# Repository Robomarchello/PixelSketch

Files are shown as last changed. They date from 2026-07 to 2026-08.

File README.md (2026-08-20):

# Digital Etch A Sketch

A digital recreation of the classic Etch A Sketch, built from scratch with a Raspberry Pi Pico.

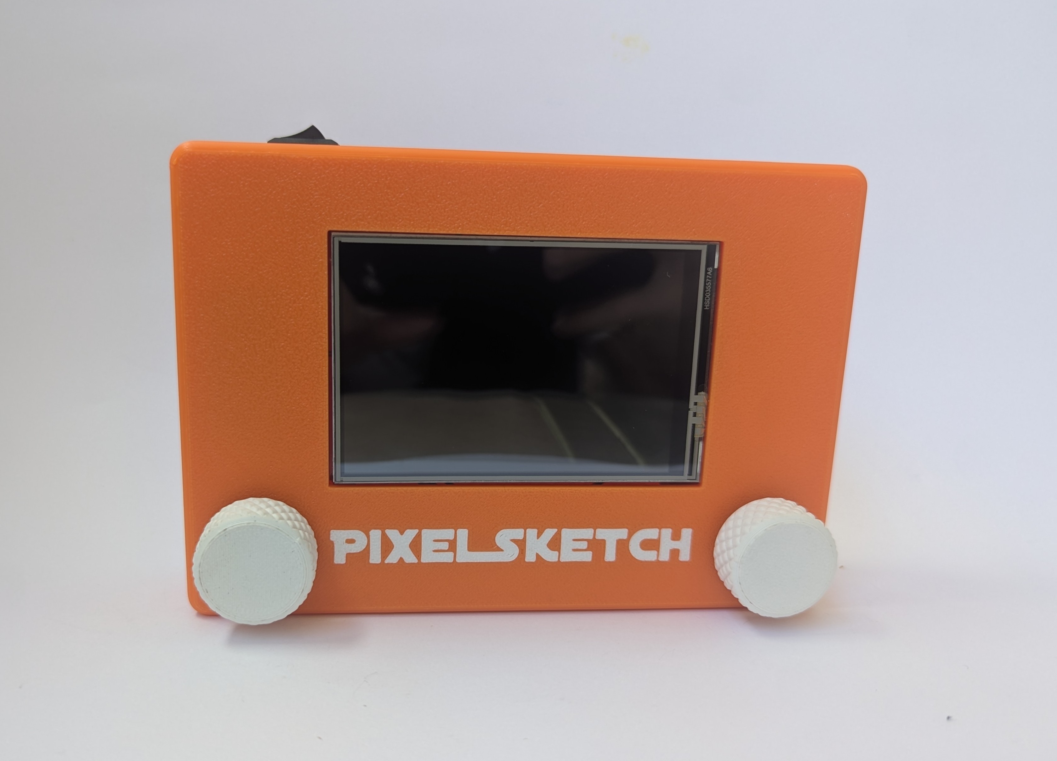
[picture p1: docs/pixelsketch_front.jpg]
front look


[View the CAD model on Onshape](https://cad.onshape.com/documents/f1feae0bb556c6484e455513/w/0b4a13cc13eba7f4db07bca6/e/b10465846ec39c7c90a8a02b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)

Wiring diagram is available in docs folder.
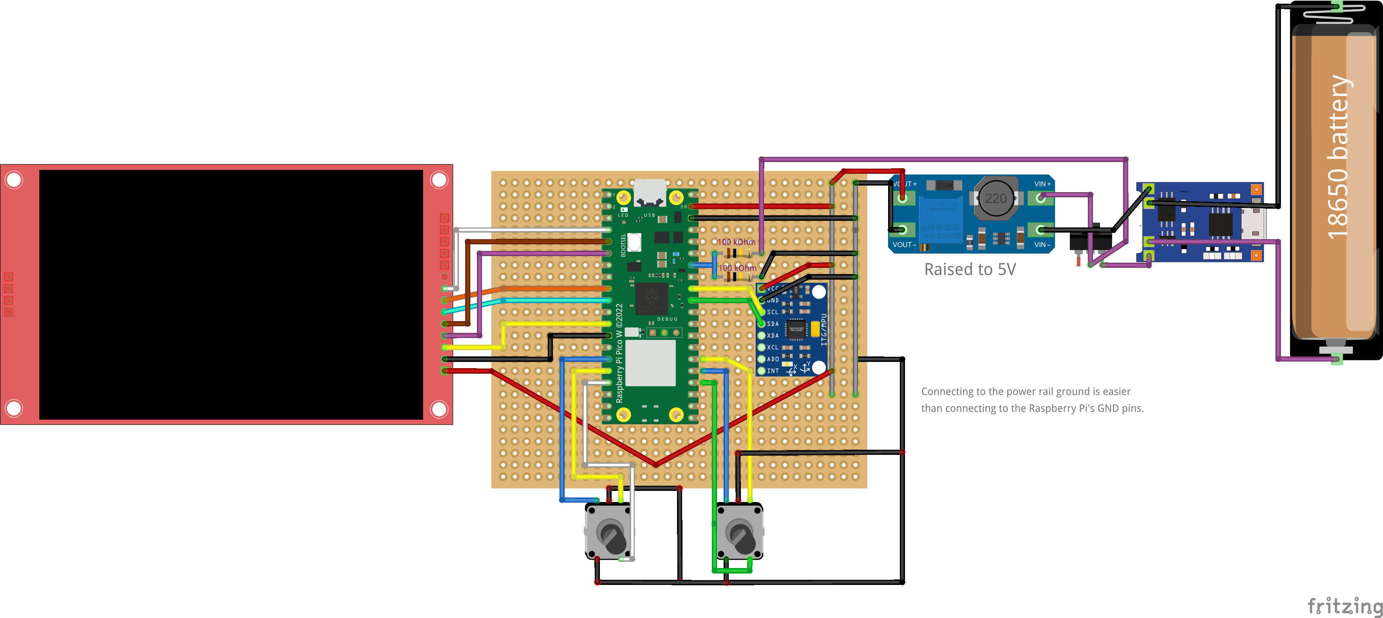
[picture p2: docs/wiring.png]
Wiring diagram

(Notice: everything should work even without boost converter) 

### Features

* 🎨 Color display
* 🎛️ Two rotary encoders for drawing
* 💾 Save drawings
* 🔋 Rechargeable battery
* 🖌️ Adjustable brush size and color
* 📦 Custom 3D-printed enclosure

## Hardware

* **Microcontroller:** Raspberry Pi Pico
* **Display:** MSP3520 3.5" SPI TFT module — ILI9488 driver
* **Rotary encoders:** 2× EC1601J-H01/15
* **Battery:** 18650 Li-ion, 1500 mAh
* **Charging module:** HW-373 (TP4056)
* **Single 18650 battery holder**
* **MPU6050**
* **70 × 90 mm Perfboard**
* **KCD11-101 Power switch**

Built as my first hardware project, using MicroPython.

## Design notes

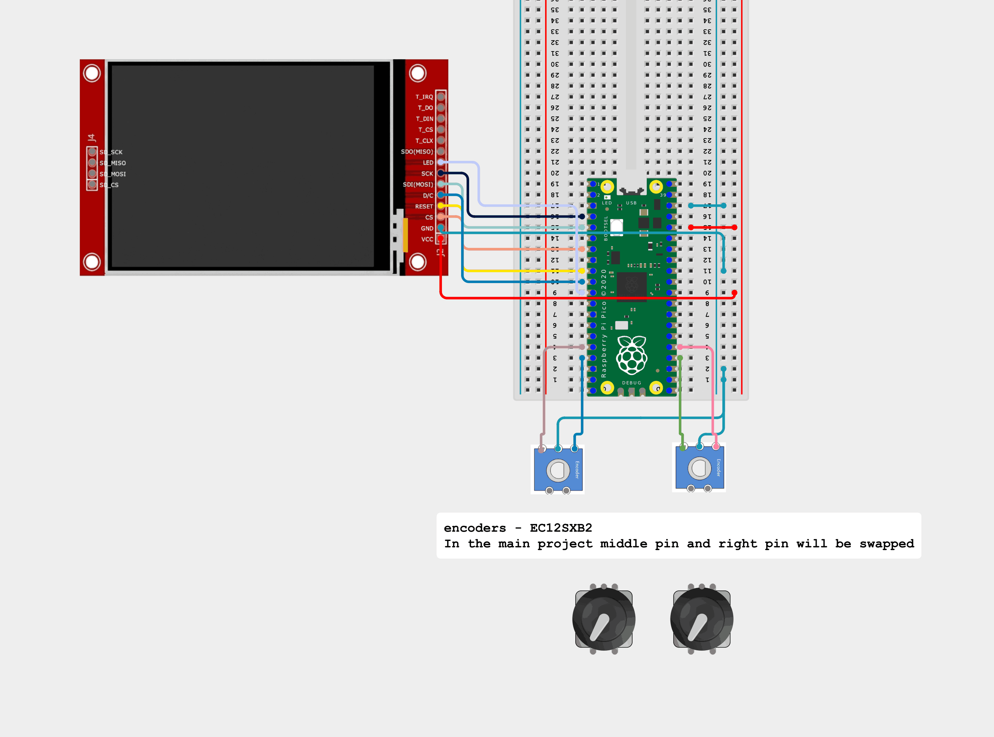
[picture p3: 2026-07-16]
images/drawing_prototype_circuit.png

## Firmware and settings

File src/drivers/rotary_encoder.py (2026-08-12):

# My rotary encoder implementation for RPI pico:)
#
# I first implemented this with a Gray-code state machine (my own design),
# which worked great on the breadboard. Once everything was soldered onto
# perfboard, the encoders started producing a different edge pattern than
# my state machine expected, so with AI's help I reworked the decoding logic
# to trigger off CLK edges directly instead. My original state-machine
# version is preserved in earlier commits.

import micropython
from machine import Pin, Timer
from utime import ticks_diff, ticks_us


class RotaryEncoder:
    DEBOUNCE_TIMER_MS = 50
    MIN_PULSE_US = 800

    def __init__(self, pin_a, pin_b, button_pin, decoding=1, default_value=0):
        self.signal_a = Pin(pin_a, Pin.IN, Pin.PULL_UP)
        self.signal_b = Pin(pin_b, Pin.IN, Pin.PULL_UP)
        self.button = Pin(button_pin, Pin.IN, Pin.PULL_UP)

        self.decoding = decoding
        self.value = default_value
        self.button_pressed = False
        self.debounce_timer = Timer(-1)
        self.func = None

        self._last_clk = self.signal_a.value()
        self._last_pulse_us = 0

        self.enable_irq()

    def enable_irq(self):
        self.signal_a.irq(
            trigger=Pin.IRQ_FALLING | Pin.IRQ_RISING,
            handler=self._handle_rot_change
        )
        self.button.irq(
            trigger=Pin.IRQ_FALLING | Pin.IRQ_RISING,
            handler=self._handle_button_change
        )

    def disable_irq(self):
        self.signal_a.irq(handler=None)
        self.button.irq(handler=None)
        self.button_pressed = False

    def _handle_rot_change(self, pin=None):
        clk = self.signal_a.value()
        if clk == self._last_clk:
            return
        self._last_clk = clk

        if clk == 0:  # act only on CLK falling edge
            now = ticks_us()
            if ticks_diff(now, self._last_pulse_us) < self.MIN_PULSE_US:
                return  # debounce
            self._last_pulse_us = now

            dt = self.signal_b.value()
            if dt == 1:
                self.value -= 1
            else:
                self.value += 1

    def _debounce_callback(self, timer):
        stable_state = not self.button.value()

        if stable_state != self.button_pressed:
            self.button_pressed = stable_state
            if self._on_change is not None:
                try:
                    self._scheduled = True
                    micropython.schedule(self._on_change, 0)
                except RuntimeError:
                    self._scheduled = False

    def _on_change(self, arg):
        if self.func is not None:
            self.func()

    def _handle_button_change(self, pin):
        self.debounce_timer.init(
            mode=Timer.ONE_SHOT,
            period=self.DEBOUNCE_TIMER_MS,
            callback=self._debounce_callback,
        )


if __name__ == '__main__':
    import utime

    SIGNAL_A_PIN = 20
    SIGNAL_B_PIN = 19
    BUTTON_PIN = 13

    encoder = RotaryEncoder(SIGNAL_A_PIN, SIGNAL_B_PIN, BUTTON_PIN, decoding=1)

    def test_func():
        global encoder
        if encoder.button_pressed:
            print('button pressed')
        else:
            print('button unpressed')

    encoder.func = test_func
    last_value = encoder.value
    while True:
        if last_value != encoder.value:
            print(encoder.value)
            last_value = int(encoder.value)
        utime.sleep(0.01)

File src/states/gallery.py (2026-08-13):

import time
import os
def file_exists(filename):
    try:
        os.stat(filename)
        return True
    except OSError:
        return False

from machine import ADC, Pin
from states.state import State
import states.drawing
from screen_manager import ScreenManager
from input_manager import InputManager
from config import *


class BatteryMeter:
    # calibrated conversion factor with multimeter to getting real voltage (2.12)
    conversion_factor = (3.3 / 65535) * 2.12791738
    VOLTAGE_LEVELS = (
        (4.08, 100),
        (3.98, 90),
        (3.88, 80),
        (3.80, 70),
        (3.73, 60),
        (3.68, 50),
        (3.61, 40),
        (3.53, 30),
        (3.42, 20),
        (3.35, 10),
    )
    def __init__(self):
        self.usb_power = Pin('WL_GPIO2', Pin.IN) 
        
        self.screen = ScreenManager.screen
        self.COLORS = ScreenManager.COLORS

        self.battery_pin = Pin(BATTERY_READING_PIN, mode=Pin.IN)
        self.adc = ADC(self.battery_pin)

        self.cell_count = 5
        self.charge_per_cell = 100 // self.cell_count
        
        self.voltage = 0.0
        self.battery_level = 0
        self.cells_filled = 0

        # for drawing
        self.bat_position = (417, 289)
        self.cell_size = (8, 20)
        self.x_spacing = 2
        self.spacing_total = self.cell_size[0] + self.x_spacing

    def draw(self):
        self.screen.fill_rect(
            self.bat_position[0], 
            self.bat_position[1], 
            (self.cell_size[0] + self.x_spacing) * self.cell_count, 
            self.cell_size[1], 
            self.COLORS['BLACK']
        )

        for i in range(self.cells_filled):
            x_offset = self.spacing_total * i
            self.screen.fill_rect(
                self.bat_position[0] + x_offset, 
                self.bat_position[1], 
                self.cell_size[0], 
                self.cell_size[1], 
                self.COLORS['WHITE']
            )

        self.screen.show_region(
            self.bat_position[0], 
            self.bat_position[1], 
            (self.cell_size[0] + self.x_spacing) * self.cell_count, 
            self.cell_size[1], 
        )

    def get_voltage(self):
        if self.usb_power.value():
            # Connected via microUSB
            self.voltage = 5.0
        else:
            raw_reading = self.adc.read_u16()

            self.voltage = raw_reading * self.conversion_factor
        self.voltage_to_battery_level()

    def voltage_to_battery_level(self):
        for voltage, charge in self.VOLTAGE_LEVELS:
            if self.voltage > voltage:
                self.battery_level = charge
                self.cells_filled = self.battery_level // self.charge_per_cell
                return
        self.battery_level = 0


class GalleryState(State):
    UI_path = 'assets/gallery.bin'
    SAVE_path = '/gallery/'
    SAVE_FOLDER_NAME = 'gallery'
    SLOTS = 5

    # I've put it here so even after exiting you get straight to the needed slot.
    slot_index = 0
    def __init__(self, state_machine):
        self.initialize_slots()
        
        self.state_machine = state_machine

        self.screen = ScreenManager.screen
        self.COLORS = ScreenManager.COLORS

        self.encoder_left = InputManager.encoder_left
        self.encoder_right = InputManager.encoder_right

        self.change_state = False
        self.encoder_left.func = self.open_draw_isr
        self.encoder_right.func = self.delete_file

        self.last_encoder_x = int(self.encoder_left.value)
        self.last_encoder_y = int(self.encoder_right.value)

        self.preview_topleft = (120, 95)
        self.infobar_topleft = (116, 
                                self.preview_topleft[1] + SCREEN_H // 2 + 10)
        self.infobar_size = (SCREEN_W // 2 + 10, 16)

        self.slot_path = None
        self.file_exists = False

        self.redraw_info = True

        self.battery_meter = BatteryMeter()

    def delete_file(self):
        if self.file_exists:
            os.remove(self.slot_path)

        self.update_file_info()

    def open_draw_isr(self):
        self.change_state = True

    def open_draw_state(self):
        if self.encoder_left.button_pressed:
            InputManager.disable_input()
            new_state = states.drawing.DrawingState(self.state_machine)

            new_state.file_exists = self.file_exists
            new_state.save_path = self.slot_path

            self.state_machine.change_state(new_state)

    def logic(self):
        curr_encoder_x = int(self.encoder_left.value)
        curr_encoder_y = int(self.encoder_right.value)

        # Calculate position change (deltas)
        dx = curr_encoder_x - self.last_encoder_x
        dy = (curr_encoder_y - self.last_encoder_y)

        if dx != 0:
            self.toggle_slot(dx)
        elif dy != 0:
            self.toggle_slot(dy)

        self.last_encoder_x = curr_encoder_x
        self.last_encoder_y = curr_encoder_y

        if self.redraw_info:
            self.write_slot_img()
            self.draw_slot_info()

            self.battery_meter.draw()

            self.redraw_info = False

        if self.change_state:
            self.open_draw_state()

    def write_slot_img(self):
        if self.file_exists:
            ScreenManager.write_image_shunk(self.slot_path, self.preview_topleft)
        else:
            ScreenManager.screen.fill_rect(
                self.preview_topleft[0], 
                self.preview_topleft[1], 
                SCREEN_W // 2, 
                SCREEN_H // 2, 
                self.COLORS['WHITE']
            )
        ScreenManager.screen.show_region(
            self.preview_topleft[0], 
            self.preview_topleft[1], 
            SCREEN_W // 2, 
            SCREEN_H // 2
        )

    def toggle_slot(self, change):
        step = 1 if change > 0 else -1
        self.slot_index = (self.slot_index + step) % self.SLOTS

        self.update_file_info()

    def update_file_info(self):
        self.slot_path = self.SAVE_path + f'slot_{self.slot_index}.bin'
        self.file_exists = file_exists(self.slot_path)
        self.redraw_info = True

    def draw_slot_info(self):
        ScreenManager.screen.fill_rect(
            self.infobar_topleft[0], 
            self.infobar_topleft[1], 
            self.infobar_size[0], 
            self.infobar_size[1], 
            self.COLORS['BLACK']
        )
        self._draw_slot_count()

        if self.file_exists:
            # Get the file statistics tuple
            file_stat = os.stat(self.slot_path)

            # Extract modification time (index 8)
            mtime = file_stat[8]
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

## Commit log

2026-07-16 Made a drawing prototype! It works!
2026-07-16 Added wiring diagram for drawing prototype
2026-07-17 Added brush tip preview for easier aiming (unoptimized, but this is prototype, sir)
2026-07-17 Project architecture:) State machine for states and started recreating prototype
2026-07-21 Added rotary encoder button capabilities
2026-07-21 brush position change by encoder value difference. (it was just copying encoder absolute value)
2026-07-22 Additional button controls: changing modes, radius, (color change in progress)
2026-07-22 drawing without skipping pixels.
    [drawing.py]
2026-07-25 Shake to clear feature. Using mpu6050 motion sensor
2026-07-27 Battery status in gallery. !!! in progress
2026-07-29 Battery status finished
2026-07-29 A way to deploy files to pico. Put UI binaries into assets folder
2026-07-29 Added a skull ascii when an error appears
    [app.py]
2026-08-12 Changes for the assembled version. Soldered everything onto the perfboard ✨
2026-08-13 Calibrated voltage conversion rate + raised shake threshold
2026-08-18 Video preparation commit:)
    [wiring.fzz]
